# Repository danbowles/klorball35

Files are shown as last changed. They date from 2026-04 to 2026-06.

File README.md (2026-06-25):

# KLORBALL35

<picture>
  <source media="(prefers-color-scheme: dark)" srcset="/docs/images/klorball35-layout-dark.svg">
  <source media="(prefers-color-scheme: light)" srcset="/docs/images/klorball35-layout-light.svg">
  Klorball35 layout
</picture>

**Klorball35** is a 35-key, column-staggered, low-profile split keyboard with an integrated optical trackball. It's derived from [KLOR](https://github.com/GEIGEIGEIST/KLOR) and [Keyball](https://github.com/Yowkees/keyball),  built with [Kivipallur](https://github.com/dr3san/Kivipallur) as a starting point in [Ergogen](https://ergogen.cache.works/), and designed around Kailh Choc V1 switches, an [0xCB Helios](https://github.com/0xCB-dev/0xCB-Helios) (RP2040) controller per half, and a PixArt **PMW3360** sensor on the right hand.

***

## LAYOUT

Each half carries a 5-column × 3-row main matrix plus a 3-key (left) and 2-key (right)thumb cluster. The right hand gives up one key to make room for the trackball, so the two halves are **18 (left) + 17 (right) = 35 keys**.

- Column-staggered, splayed columns with per-column stagger/splay tuning
- Kailh Choc V1 (low-profile) switches, 18 × 17 mm spacing
- TRRS jack for the inter-half connection
- M2 mounting holes and a matching FR4 switchplate per half
- PMW3360 optical trackball on the right half via the *Kivipallur* breakout

***

## IMAGES

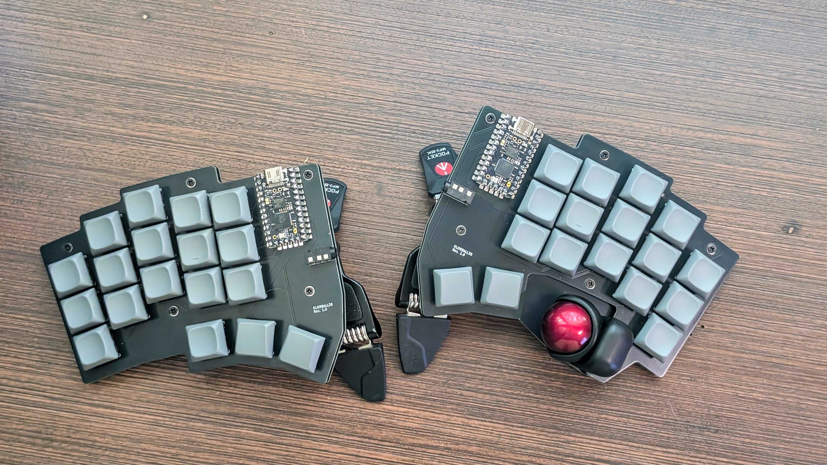
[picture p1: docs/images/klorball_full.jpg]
Klorball35 fully assembled


▲ The assembled Klorball35.

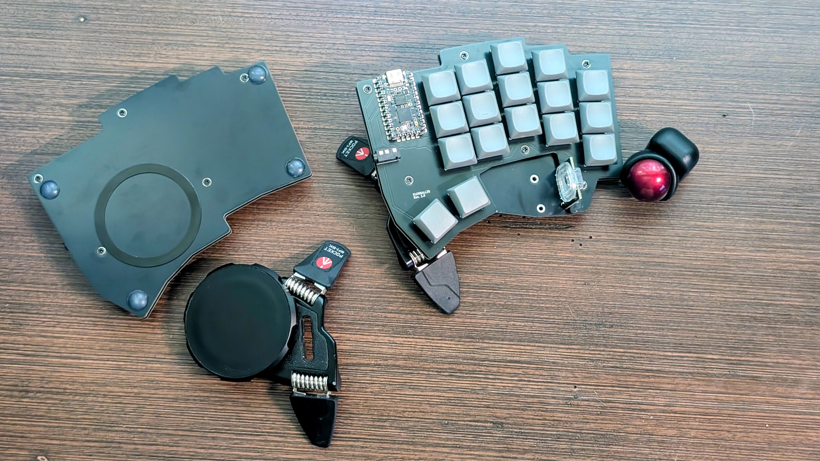
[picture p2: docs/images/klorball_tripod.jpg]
Klorball35 mounted on a tripod


▲ Mounted on a tripod.

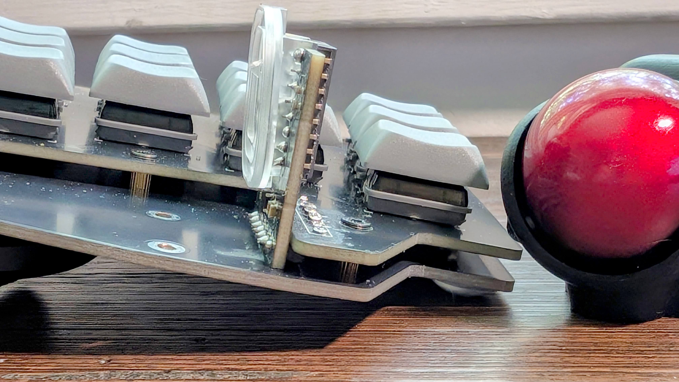
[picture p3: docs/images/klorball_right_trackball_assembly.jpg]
Klorball35 right-half trackball assembly


▲ The right-half trackball assembly.

***

## PCB

[`kicad/`](/kicad/) holds the KiCad 9 projects:

| Project | Description |
| --- | --- |
| [`klorball35_left`](/kicad/klorball35_left/) | Left-half PCB + schematic |
| [`klorball35_right`](/kicad/klorball35_right/) | Right-half PCB + schematic (trackball) |
| [`klorball35_plate_left`](/kicad/klorball35_plate_left/) | Left FR4 switchplate |
| [`klorball35_plate_right`](/kicad/klorball35_plate_right/) | Right FR4 switchplate |
| [`Kivipallur_PMW3360_breakout`](/kicad/Kivipallur_PMW3360_breakout/) | PMW3360 trackball sensor breakout |

Shared footprint and symbol libraries (`Keebio-Parts.pretty`, `keyswitches.pretty`, `Helios.pretty`, `Mounting_Hole.pretty`, etc.) live alongside the projects.

Manufacturing **Gerbers** are in [`gerbers/`](/gerbers/):

- `GERBER-klorball35_left.zip` / `GERBER-klorball35_right.zip` — main PCBs
- `GERBER-klorball35_plate_left.zip` / `GERBER-klorball35_plate_right.zip` — FR4 switchplates
- `GERBER-Kivipallur_PMW3360_breakout.zip` (+ BOM and CPL CSVs) — trackball breakout

***

## SOURCE

The whole board is generated from a single Ergogen definition, [`config.yml`](/config.yml) (Ergogen `4.2.1`). Regenerate the outlines and PCB scaffolds with:

```sh
ergogen config.yml --svg -o output
```

Outputs land in [`output/`](/output/) (`outlines/` as DXF/SVG and `pcbs/` as KiCad files), which are then finished by hand in KiCad.

***

## SWITCHPLATE

A matching FR4 switchplate is generated for each half (`klorball35_plate_left` / `klorball35_plate_right`, with Gerbers in `gerbers/`). The plate outline is shared with the main board; only the key cutouts and M2 screw holes differ.

***

## TRACKBALL

The right half integrates a PixArt **PMW3360DM-T2QU** optical sensor on the *Kivipallur* breakout ([`kicad/Kivipallur_PMW3360_breakout`](/kicad/Kivipallur_PMW3360_breakout/)). It connects to the right-hand Helios over SPI through the breakout slot in the PCB.

***

## FIRMWARE

Each half runs on an [0xCB Helios](https://github.com/0xCB-dev/0xCB-Helios) RP2040 controller (Pro Micro-compatible footprint), so the board can run **QMK** or **ZMK**. A dedicated Klorball35 firmware config isn't published yet; the stock [KLOR QMK config](https://github.com/GEIGEIGEIST/qmk-config-klor) and [KLOR ZMK config](https://github.com/GEIGEIGEIST/zmk-config-klor) are good starting points, with the matrix and the PMW3360 trackball wired up to match this board.

***

## CREDITS

- **[KLOR](https://github.com/GEIGEIGEIST/KLOR)** by [GEIGEIGEIST](https://github.com/GEIGEIGEIST) — One of the best keyboards I have used.
- **[0xCB Helios](https://github.com/0xCB-dev/0xCB-Helios)** by [0xCB](https://github.com/0xCB-dev) — the RP2040 controller.
- **[Ergogen](https://github.com/ergogen/ergogen)** by [MrZealot](https://github.com/mrzealot) — the keyboard generator.
- **[Kivipallur](https://github.com/dr3san/Kivipallur)** by [dr3san](https://github.com/dr3san) — the board that got this project started.
- **[25mm Trackball Housing](https://www.thingiverse.com/thing:6719828)** by [kepeo](https://www.thingiverse.com/kepeo/designs)
- The **Keebio** footprint library and the PixArt PMW3360 breakout that the Kivipallur design is based on.

Built by **danbowles**.

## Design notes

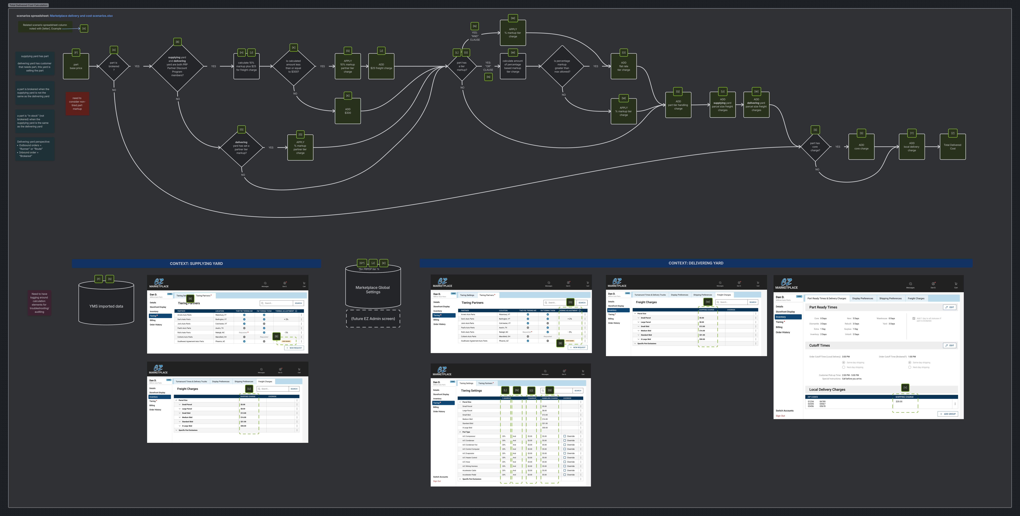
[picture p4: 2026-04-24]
kicad/klorball35_plate_left/EZ Marketplace - Task Level Flows.png

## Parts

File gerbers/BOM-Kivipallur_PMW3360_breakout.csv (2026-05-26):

Comment | Designator | Footprint | LCSC | Quantity
100n | C4 | C_0603_1608Metric_Pad1.08x0.95mm_HandSolder | C1590 | 1
10k | R2 | R_0603_1608Metric_Pad0.98x0.95mm_HandSolder | C15401 | 1
10n | C3 | C_0603_1608Metric_Pad1.08x0.95mm_HandSolder | C1589 | 1
1u | C2 | C_0603_1608Metric_Pad1.08x0.95mm_HandSolder | C1592 | 1
2.2u | C1 | C_0603_1608Metric_Pad1.08x0.95mm_HandSolder | C1607 | 1
39R | R1 | R_0603_1608Metric_Pad0.98x0.95mm_HandSolder | C23154 | 1
4.7u | C5 | C_0603_1608Metric_Pad1.08x0.95mm_HandSolder | C1705 | 1
LP2985-1.8 | U1 | SOT-23-5 | C527413 | 1

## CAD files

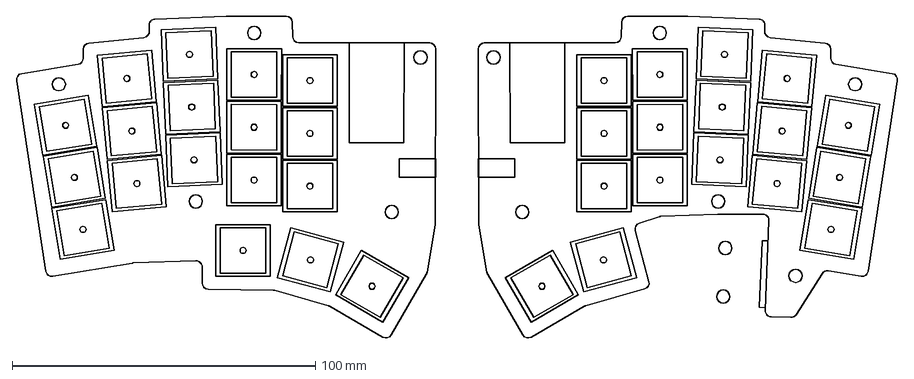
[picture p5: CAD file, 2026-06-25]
output/outlines/combo_left_right.dxf
290.7 x 106.4 mm

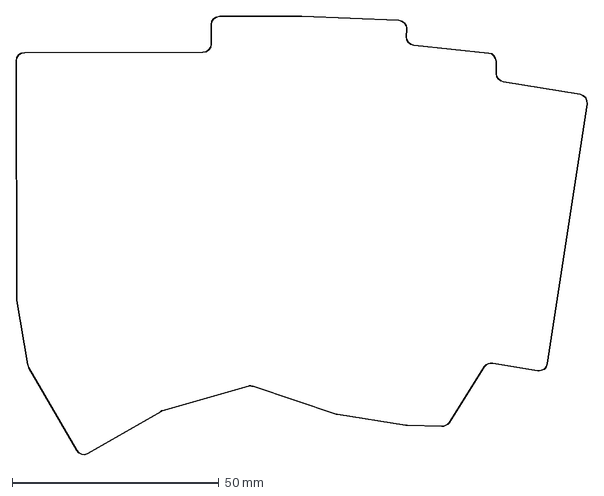
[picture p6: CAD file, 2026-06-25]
output/outlines/plate_right.dxf
138.3 x 106.4 mm

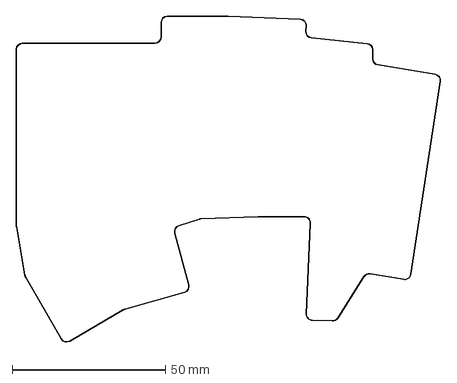
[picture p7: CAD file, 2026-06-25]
output/outlines/board_right.dxf
138.3 x 106.4 mm

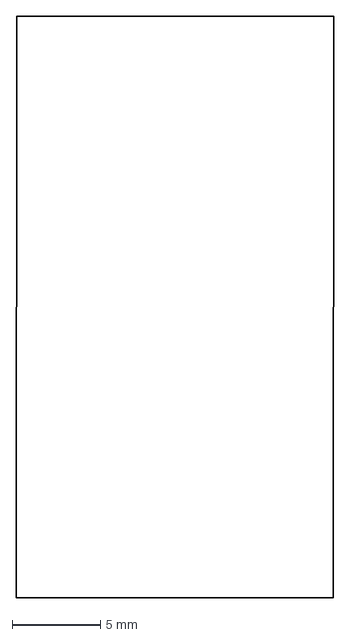
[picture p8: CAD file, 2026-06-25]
output/outlines/helios_left.dxf
18.0 x 33.0 mm

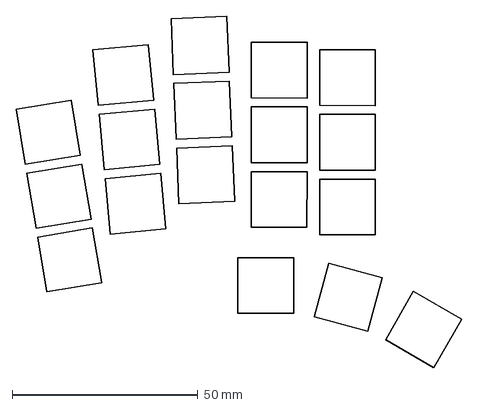
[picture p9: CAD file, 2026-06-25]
output/outlines/switches_left.dxf
119.9 x 94.5 mm

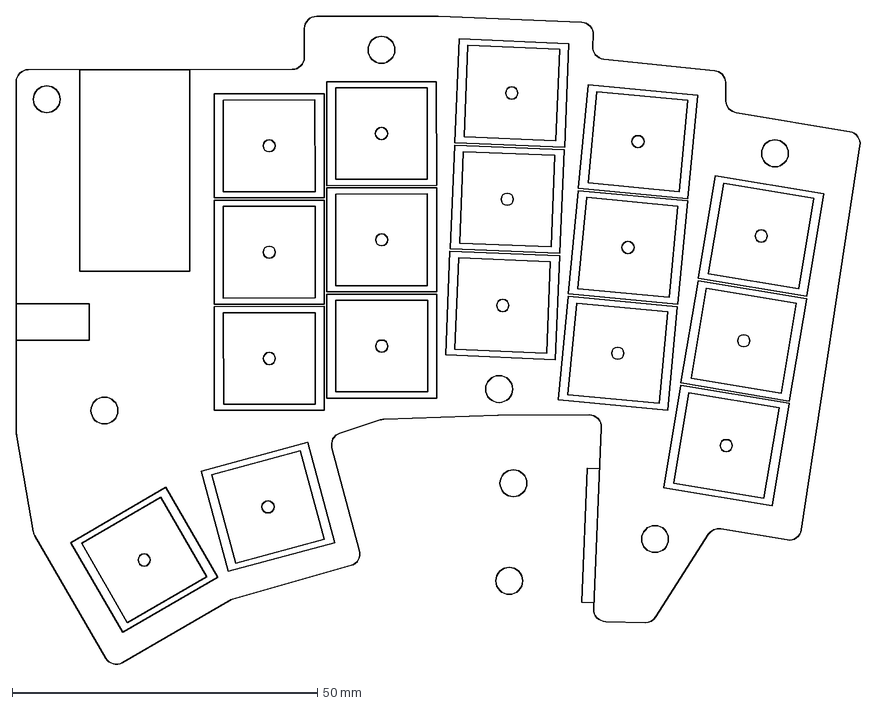
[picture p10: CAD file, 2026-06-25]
output/outlines/combo_right.dxf
138.3 x 106.4 mm

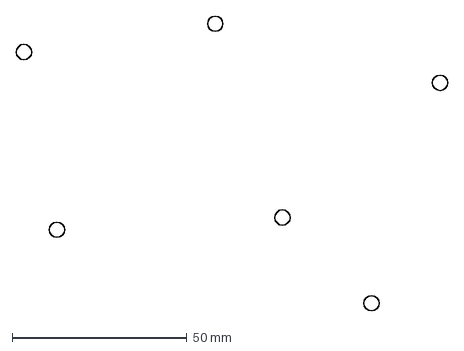
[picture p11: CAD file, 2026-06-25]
output/outlines/holes_right.dxf
123.6 x 84.5 mm

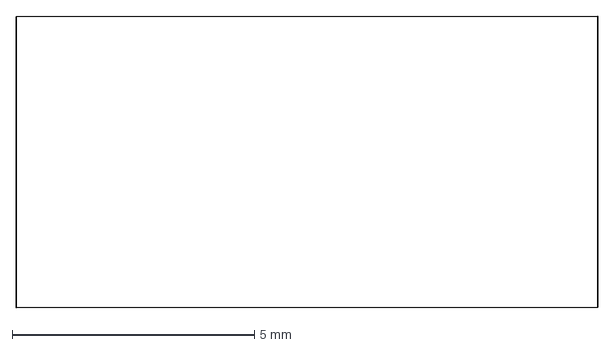
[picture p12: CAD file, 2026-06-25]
output/outlines/trrs_right.dxf
12.0 x 6.01 mm

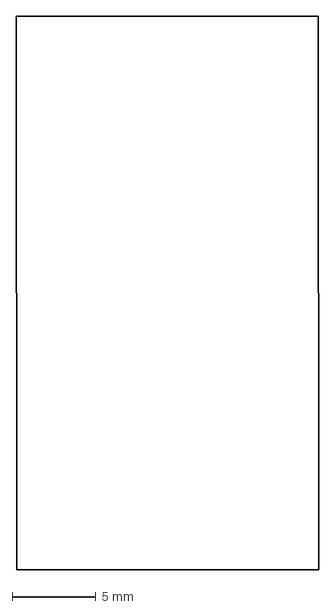
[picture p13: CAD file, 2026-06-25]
output/outlines/helios_right.dxf
18.0 x 33.0 mm

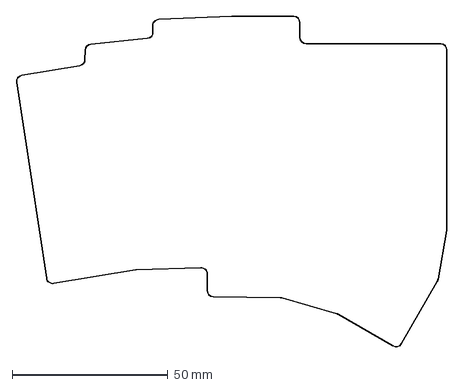
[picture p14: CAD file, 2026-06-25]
output/outlines/board_left.dxf
138.3 x 106.4 mm

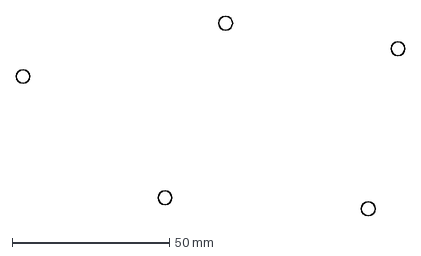
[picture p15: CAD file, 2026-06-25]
output/outlines/holes_left.dxf
123.6 x 63.4 mm

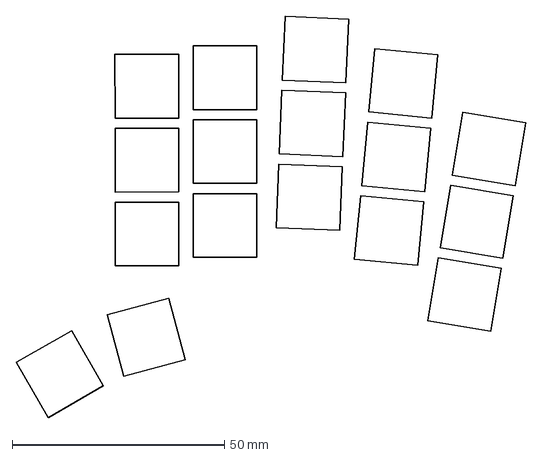
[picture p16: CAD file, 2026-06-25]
output/outlines/switches_right.dxf
119.9 x 94.5 mm

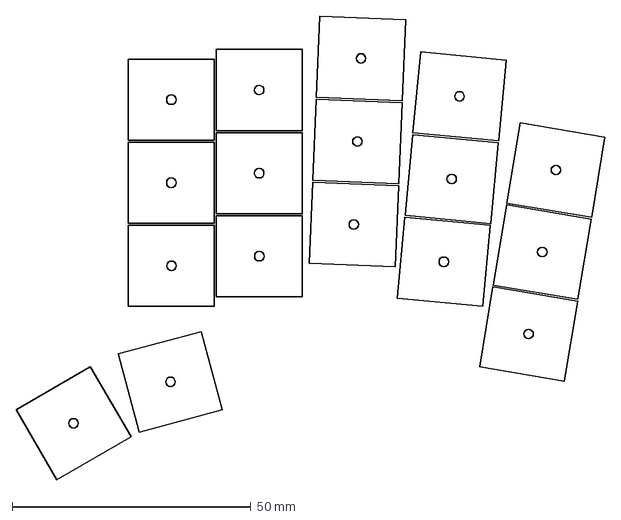
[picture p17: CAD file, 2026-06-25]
output/outlines/keycaps_right.dxf
123.3 x 97.2 mm

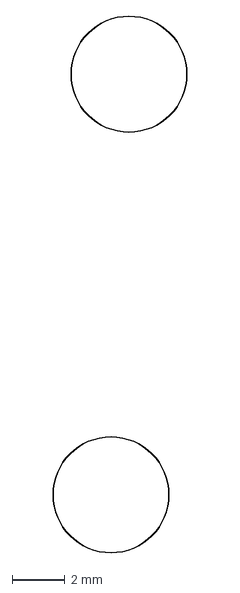
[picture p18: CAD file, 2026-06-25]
output/outlines/plate_holes_right.dxf
5.08 x 20.4 mm

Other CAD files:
output/outlines/combo_left.dxf
output/outlines/trackball_breakout_right.dxf
output/outlines/keycaps_left.dxf
output/outlines/trrs_left.dxf

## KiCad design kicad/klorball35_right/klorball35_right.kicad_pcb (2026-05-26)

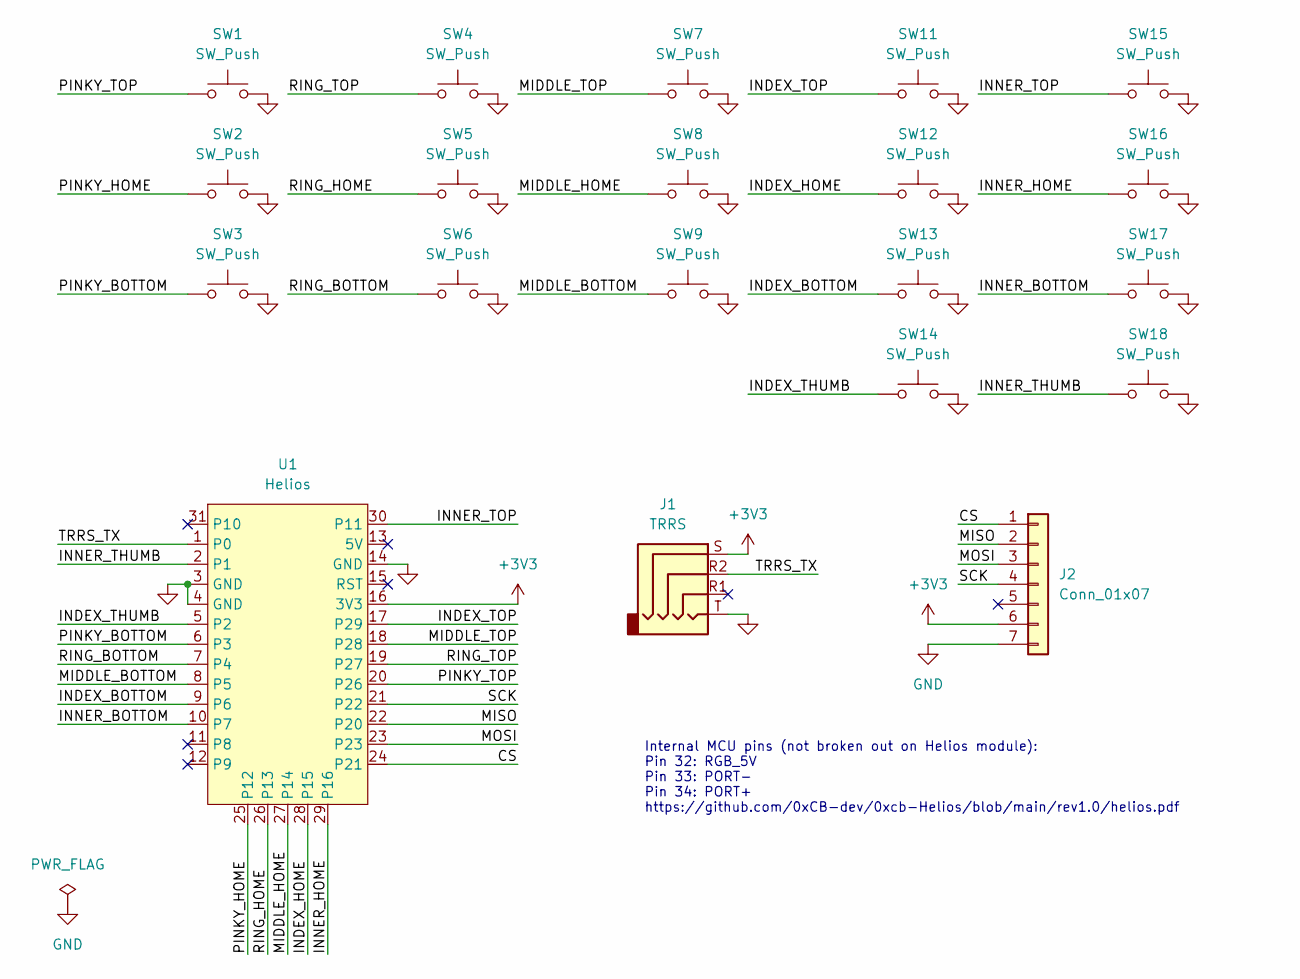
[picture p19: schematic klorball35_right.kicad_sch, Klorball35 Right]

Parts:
J1: TRRS; TRRS-PJ-320A
J2: Conn_01x07; PinHeader_1x07_P2.54mm_Vertical
SW1, SW2, SW3, SW4, SW5, SW6, SW7, SW8, SW9, SW11, SW12, SW13, SW14, SW15, SW16, SW17, SW18: SW_Push; Kailh_socket_PG1350_optional
U1: Helios; Helios_ACH

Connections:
+3V3: J1.S, J2.6, U1.16 (3V3)
/CS: J2.1, U1.24 (P21)
/INDEX_BOTTOM: SW13.1, U1.9 (P6)
/INDEX_HOME: SW12.1, U1.28 (P15)
/INDEX_THUMB: SW14.1, U1.5 (P2)
/INDEX_TOP: SW11.1, U1.17 (P29)
/INNER_BOTTOM: SW17.1, U1.10 (P7)
/INNER_HOME: SW16.1, U1.29 (P16)
/INNER_THUMB: SW18.1, U1.2 (P1)
/INNER_TOP: SW15.1, U1.30 (P11)
/MIDDLE_BOTTOM: SW9.1, U1.8 (P5)
/MIDDLE_HOME: SW8.1, U1.27 (P14)
/MIDDLE_TOP: SW7.1, U1.18 (P28)
/MISO: J2.2, U1.22 (P20)
/MOSI: J2.3, U1.23
/PINKY_BOTTOM: SW3.1, U1.6 (P3)
/PINKY_HOME: SW2.1, U1.25 (P12)
/PINKY_TOP: SW1.1, U1.20 (P26)
/RING_BOTTOM: SW6.1, U1.7 (P4)
/RING_HOME: SW5.1, U1.26 (P13)
/RING_TOP: SW4.1, U1.19 (P27)
/SCK: J2.4, U1.21 (P22)
/TRRS_TX: J1.R2, U1.1 (P0)
GND: J1.T, J2.7, SW1.2, SW2.2, SW3.2, SW4.2, SW5.2, SW6.2, SW7.2, SW8.2, SW9.2, SW11.2, SW12.2, SW13.2, SW14.2, SW15.2, SW16.2, SW17.2, SW18.2, U1.3 (GND), U1.4 (GND), U1.14 (GND)

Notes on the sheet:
Internal MCU pins (not broken out on Helios module): Pin 32: RGB_5V Pin 33: PORT- Pin 34: PORT+ https://github.com/0xCB-dev/0xcb-Helios/blob/main/rev1.0/helios.pdf

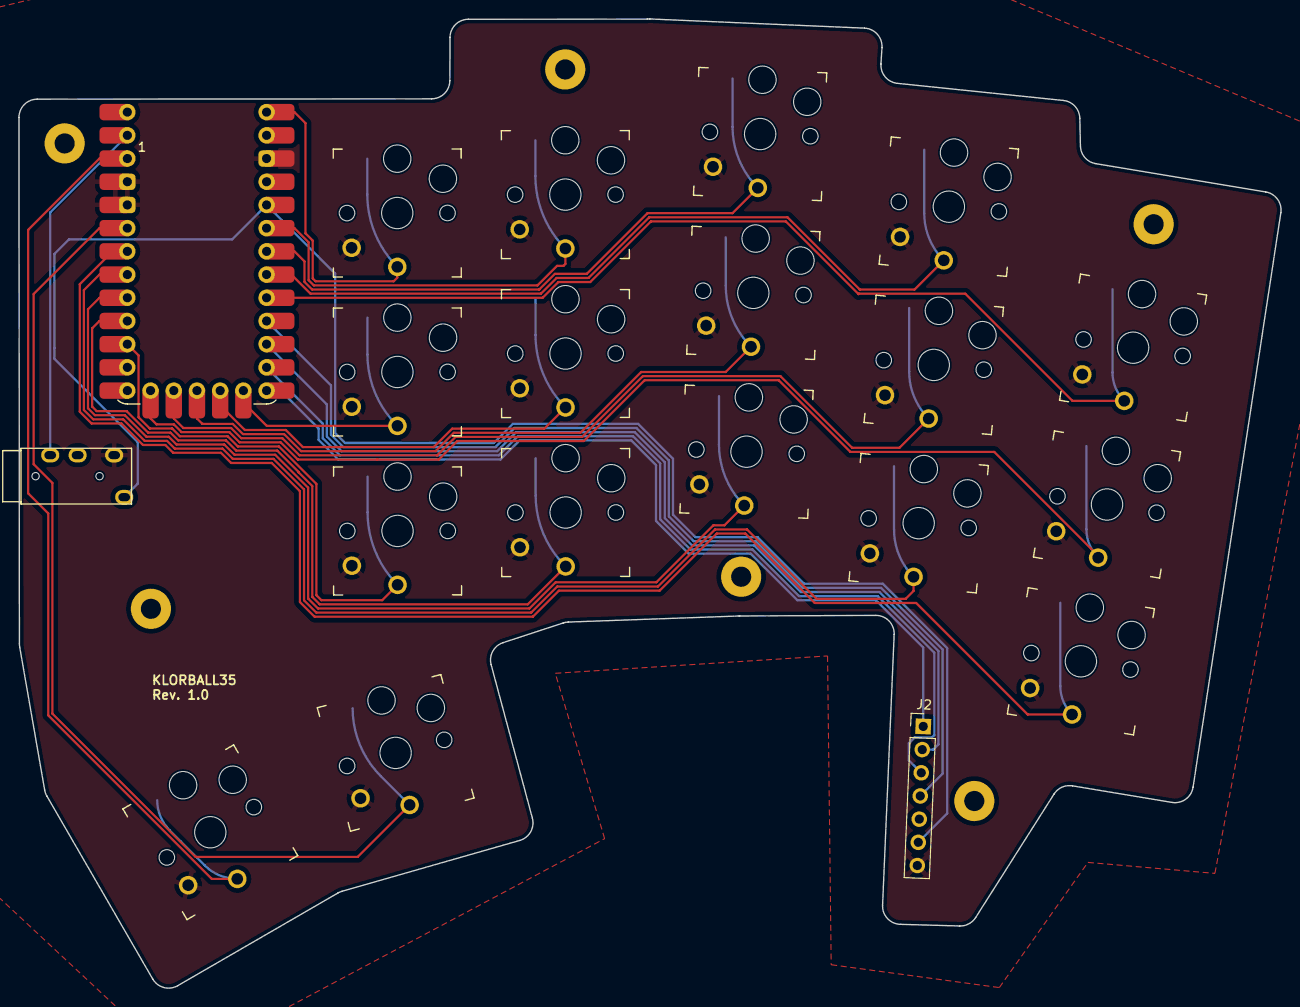
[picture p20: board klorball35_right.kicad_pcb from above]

Board: 2 copper layers, 138.1 x 106.1 mm, 26 parts (0 on the bottom side), 24 nets.

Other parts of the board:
H7, H7#2, H7#3, H7#4, H7#5, H7#6: MountingHole; MountingHole_2.2mm_M2_Pad

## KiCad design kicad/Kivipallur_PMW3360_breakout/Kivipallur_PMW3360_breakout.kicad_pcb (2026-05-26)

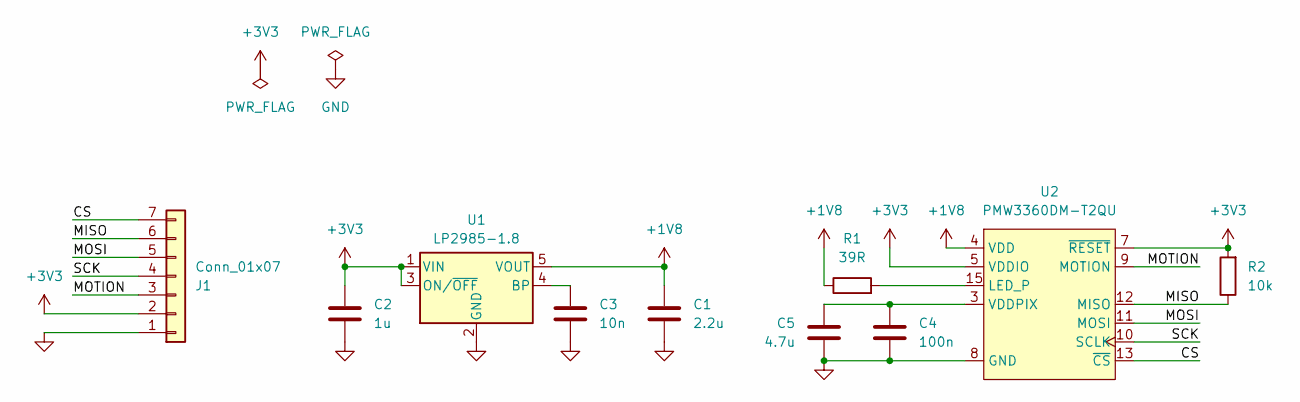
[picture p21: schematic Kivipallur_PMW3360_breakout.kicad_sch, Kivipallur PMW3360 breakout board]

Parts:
C1: 2.2u; C_0603_1608Metric_Pad1.08x0.95mm_HandSolder
C2: 1u; C_0603_1608Metric_Pad1.08x0.95mm_HandSolder
C3: 10n; C_0603_1608Metric_Pad1.08x0.95mm_HandSolder
C4: 100n; C_0603_1608Metric_Pad1.08x0.95mm_HandSolder
C5: 4.7u; C_0603_1608Metric_Pad1.08x0.95mm_HandSolder
J1: Conn_01x07; PinHeader_1x07_P2.54mm_Vertical
R1: 39R; R_0603_1608Metric_Pad0.98x0.95mm_HandSolder
R2: 10k; R_0603_1608Metric_Pad0.98x0.95mm_HandSolder
U1: LP2985-1.8; SOT-23-5
U2: PMW3360DM-T2QU; PMW3360DM-T2QU 16Pin

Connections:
+1V8: C1.1, R1.1, U1.5 (VOUT), U2.4 (VDD)
+3V3: C2.1, J1.2, R2.2, U1.1 (VIN), U1.3 (ON/~OFF), U2.5 (VDDIO), U2.7 (~RESET)
/CS: J1.7, U2.13 (~CS)
/MISO: J1.6, R2.1, U2.12 (MISO)
/MOSI: J1.5, U2.11 (MOSI)
/MOTION: J1.3, U2.9 (MOTION)
/SCK: J1.4, U2.10 (SCLK)
GND: C1.2, C2.2, C3.2, C4.1, C5.2, J1.1, U1.2 (GND), U2.8 (GND)
unnamed: C3.1, U1.4 (BP)
unnamed: R1.2, U2.15 (LED_P)
unnamed: C4.2, C5.1, U2.3 (VDDPIX)

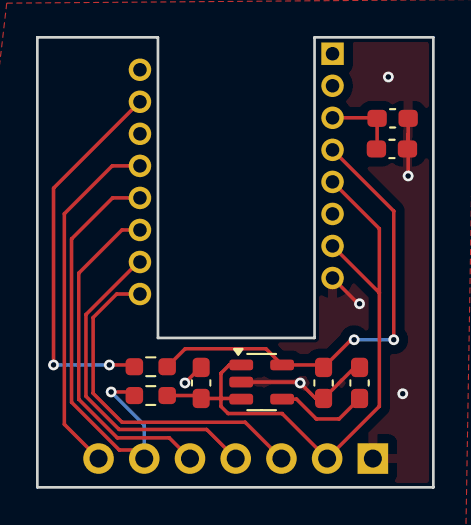
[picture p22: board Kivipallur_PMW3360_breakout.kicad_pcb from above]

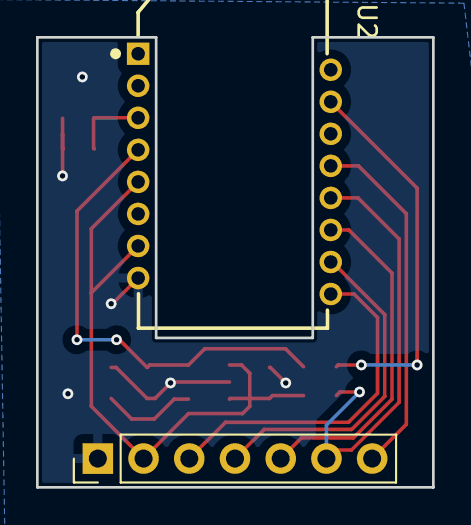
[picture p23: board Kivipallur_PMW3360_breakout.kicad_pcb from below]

Board: 2 copper layers, 22.0 x 25.0 mm, 10 parts (2 on the bottom side), 11 nets.

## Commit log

2025-12-15 🎉 Initial commit.
2025-12-29 ✨ Attempting the board design
2026-01-04 ✨ Board outline
2026-01-04 ✨ Trackball on the right!
2026-01-05 ✨ Left+right combo
2026-01-11 🔧 Mounting holes done for now.
2026-01-12 🎨 Fixing up holes for trackball mount
2026-01-12 📱 PCB'ing
2026-01-18 Initial commit of PCB+pinky switches placed
    [Kivipallur_PMW3360_breakout.kicad_pcb, Kivipallur_PMW3360_breakout.kicad_sch, klorball35_left.kicad_pcb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]
2026-02-07 Finishing footprints on left, starting schema
    [klorball35_left.kicad_pcb, klorball35_left.kicad_sch]
2026-04-24 Finishing left, start of right
    [klorball35_left.kicad_pcb, klorball35_plate_left.kicad_pcb, klorball35_plate_left.kicad_sch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]
2026-05-12 finishing right, start of gerbers
    [klorball35_left-B_Cu.gbr, klorball35_left-B_Mask.gbr, klorball35_left-B_Paste.gbr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]
2026-05-26 Wrapping up, re-organizing. Final gerbers and designs
    [BOM-Kivipallur_PMW3360_breakout.csv, Kivipallur_PMW3360_breakout.kicad_pcb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]
2026-06-25 📝 Updating readme and images
    [Klorball35_left.kicad_pcb, Klorball35_plate_left.kicad_pcb, Klorball35_plate_right.kicad_pcb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]
